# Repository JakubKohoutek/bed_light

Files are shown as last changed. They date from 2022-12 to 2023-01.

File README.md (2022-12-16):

# WiFi enabled bed light

LED light triggered by PIR motion sensor and connected to Alexa using ESP8266.
Original purpose is the night light under the bed, but the usage is actually universal.

## Circuit Diagram

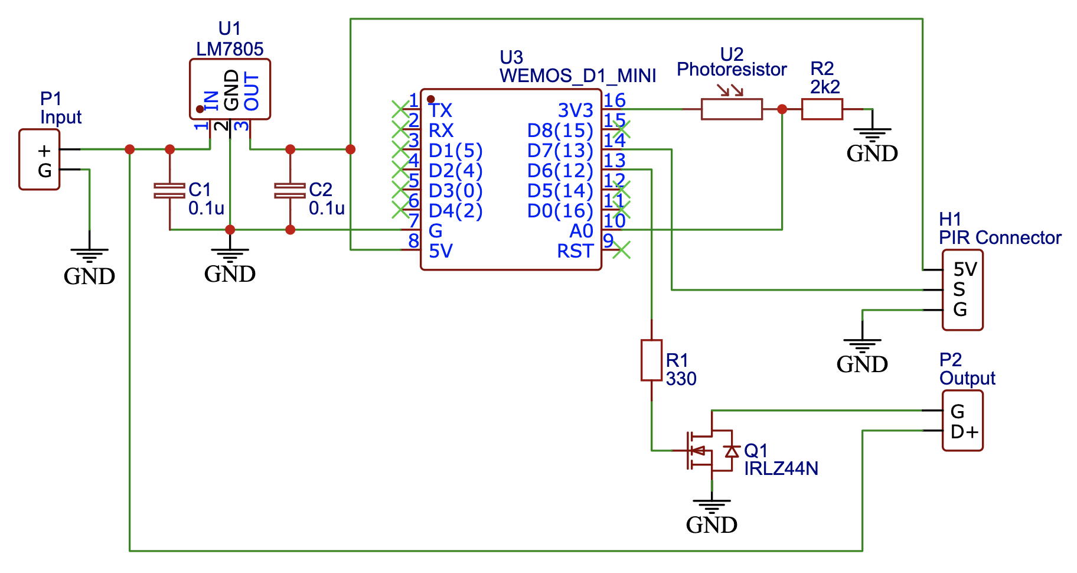
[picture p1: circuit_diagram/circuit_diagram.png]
Circuit Diagram


## Remote console

When the module is connected to WiFi, there is a remote console available at the
http://\<Device IP\>/webserial url. The list of possible commands is provided when the `help`
command is sent there.

## PIR Sensor vs WiFi

During the testing, I realized the PIR sensor is very sensitive and there are
many false triggers. The main reason is actually the WiFi of the ESP8266 - the
noise caused by the WiFi chip is triggering the sensor if there is some spike
in the network activity.

There are several measures I've taken to prevent this from happening:
- Include ferrite bead and capacitors on the PIR's supply voltage and signal
  line, just as [this article](https://www.kevindarrah.com/wiki/index.php?title=TrigBoardMotion)
  suggests.
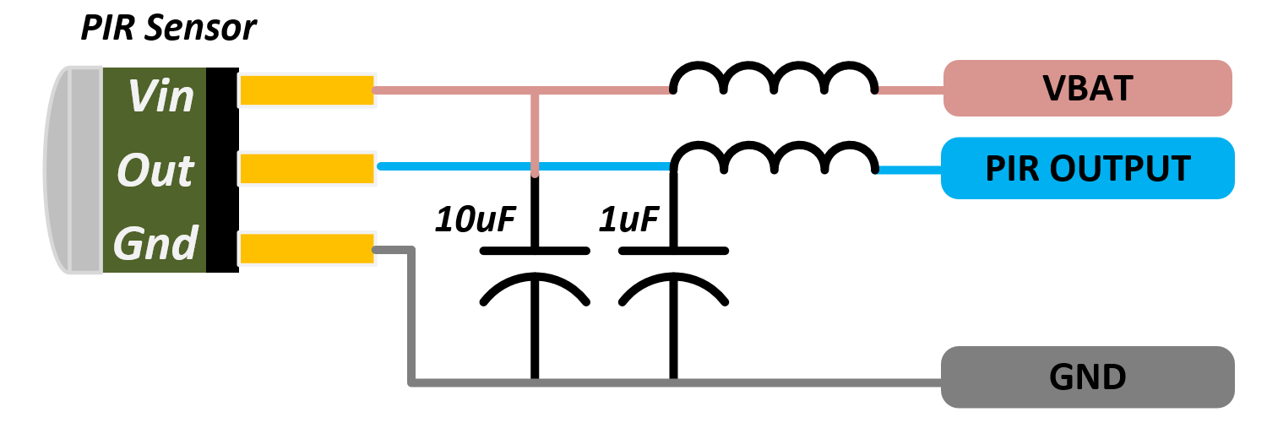
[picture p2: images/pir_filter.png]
PIR filter diagram
  
- Use grounded copper tape to cover the power and signal traces on the PCB leading to the PIR sensor
- Wrapped the head of the PIR sensor with the copper tape and used a piece of tube on
  the sensor head (that blocks the IR light) to block the IR noise

These measures reduced the amount of false triggers to a minimum, almost zero.

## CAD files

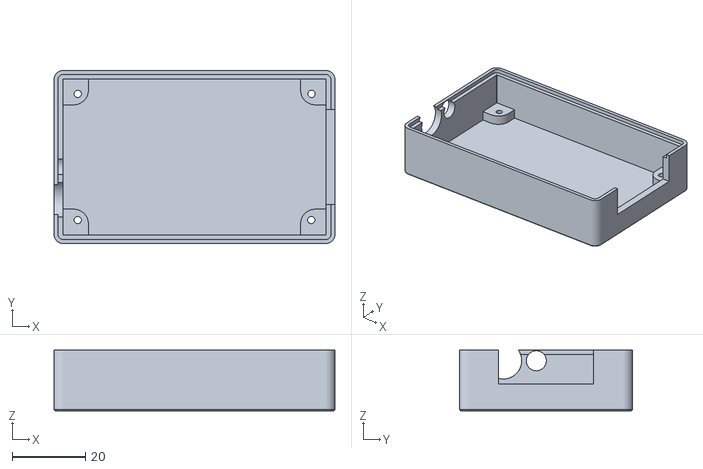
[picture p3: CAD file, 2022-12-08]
housing_model/Lower_part_v1.stl
76.8 x 47.3 x 16.6

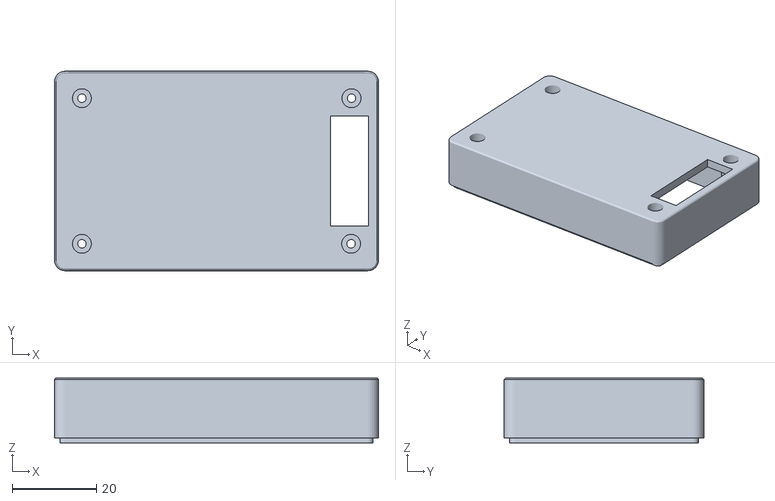
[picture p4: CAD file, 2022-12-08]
housing_model/Upper_part_v1.stl
76.8 x 47.3 x 15.4

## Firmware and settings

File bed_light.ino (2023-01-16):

#include <ESP8266WiFi.h>
#include <ESPAsyncWebServer.h>
#include <fauxmoESP.h>
#include <WebSerial.h>
#include <credentials.h>
#include "ota.h"
#include "memory.h"

#define LED_PIN D6
#define PIR_PIN D7
#define LDR_PIN A0

enum State { steady, fadingIn, fadingOut };

fauxmoESP      fauxmo;
AsyncWebServer server(80);
const char*    ssid                     = STASSID;
const char*    password                 = STAPSK;
const char*    deviceId                 = "Jacob's bed light";
State          currentState             = steady;
int            ledStripBrightness       = 0;
int            brightnessMemoryAddress  = 0;
int            thresholdMemoryAddress   = 4;
int            falseAlertsMemoryAddress = 8;
int            timeoutMemoryAddress     = 12;
int            badAlarmThresholdAddress = 16;
int            maximumBrightness        = 255;
int            roomBrightness           = 0;
int            roomBrightnessThreshold  = 100;
int            timeOfLastProcessing     = millis();
int            timeOfLastTrigger        = millis();
int            timeOflastInterrupt      = 0;
int            timeOfSensorSwitchOff    = 0;
bool           controlledByAssistant    = false;
int            falsePositivesCount      = 0;
int            lastFalsePositivesCount  = 0;
int            lightOnTimeout           = 30 * 1000;
boolean        isDelayedSwitchOff       = false;
int            falseAlarmThreshold      = 6320;

volatile boolean hasInterruptToProcess  = false;

void turnOffWiFi() {
    WiFi.disconnect();
    WiFi.mode(WIFI_OFF);
}

void turnOnWiFi() {
    WiFi.mode(WIFI_STA);
    WiFi.begin(ssid, password);
    while (WiFi.status() != WL_CONNECTED){
        delay(500);
    }
}

void ICACHE_RAM_ATTR handleSensorChange() {
    hasInterruptToProcess = true;
}

void setup() {
    pinMode(LED_PIN,     OUTPUT);
    pinMode(PIR_PIN,     INPUT);
    pinMode(LED_BUILTIN, OUTPUT);

    turnOnWiFi();

    // Inititate eeprom memory
    initiateMemory();

    // erase memory, only on the first upload
    // writeToMemory(brightnessMemoryAddress, 0);
    // writeToMemory(thresholdMemoryAddress, roomBrightnessThreshold);
    // writeToMemory(timeoutMemoryAddress, lightOnTimeout);
    // writeToMemory(badAlarmThresholdAddress, falseAlarmThreshold);

    maximumBrightness = readFromMemory(brightnessMemoryAddress);
    roomBrightnessThreshold = readFromMemory(thresholdMemoryAddress);
    lastFalsePositivesCount = readFromMemory(falseAlertsMemoryAddress);
    writeToMemory(falseAlertsMemoryAddress, 0);
    lightOnTimeout = readFromMemory(timeoutMemoryAddress);
    falseAlarmThreshold = readFromMemory(badAlarmThresholdAddress);

    // Initiate over the air programming
    OTA::initialize(deviceId);

    // Configure connection to home assistants
    fauxmo.createServer(false);
    fauxmo.setPort(80);
    fauxmo.addDevice(deviceId);
    fauxmo.enable(true);

    fauxmo.onSetState([](unsigned char device_id, const char * device_name, bool switchedOn, unsigned char value) {
        String statusMessage = String("[MAIN] Device ") + "device_id" + "(" + device_name + ") state: " + (switchedOn ? "ON" : "OFF") + ", value: " + value;
        WebSerial.println(statusMessage);

        maximumBrightness = value;
        writeToMemory(brightnessMemoryAddress, value);
        controlledByAssistant = switchedOn;
        if (switchedOn) {
            currentState = fadingIn;
        } else {
            currentState = fadingOut;
        }
    });

    // WebSerial is accessible at "<IP Address>/webserial" in browser
    WebSerial.begin(&server);
    WebSerial.msgCallback(handleWebSerialMessage);

    server.on("/index.html", HTTP_GET, [](AsyncWebServerRequest *request){
        request->send(200, "text/plain", (String("The room brightness is ") + String(roomBrightness)).c_str());
    });

    server.onRequestBody([](AsyncWebServerRequest *request, uint8_t *data, size_t len, size_t index, size_t total) {
        if (fauxmo.process(request->client(), request->method() == HTTP_GET, request->url(), String((char *)data))) return;
        // Handle any other body request here...
    });

    server.onNotFound([](AsyncWebServerRequest *request) {
        String body = (request->hasParam("body", true)) ? request->getParam("body", true)->value() : String();
        if (fauxmo.process(request->client(), request->method() == HTTP_GET, request->url(), body)) return;
        request->send(404, "text/plain", "Sorry, not found. Did you mean to go to /webserial ?");
    });

    server.begin();

    attachInterrupt(PIR_PIN, handleSensorChange, CHANGE);
}

void handleWebSerialMessage(uint8_t *data, size_t len){
    // Process message into command:value pair  
    String command = "";
    String value   = "";
    boolean beforeColon = true;
    for(int i=0; i < len; i++){
        if (char(data[i]) == ':'){
            beforeColon = false;
        } else if (beforeColon) {
            command += char(data[i]);
        } else {
            value += char(data[i]);
        }
    }

    if(command.equals("setBrightnessThreshold")) {
        WebSerial.println(String("Setting brightness threshold to ") + value.toInt());
        roomBrightnessThreshold = value.toInt();
        writeToMemory(thresholdMemoryAddress, roomBrightnessThreshold);
    } else
    if(command.equals("getBrightnessThreshold")) {
        WebSerial.println(String("Brightness threshold is ") + roomBrightnessThreshold);
    } else 
    if(command.equals("getBrightness")) {
        WebSerial.println(String("Brightness is ") + readRoomBrightness());
    } else 
    if(command.equals("sleepWiFi")) {
        WebSerial.println("Putting WiFi to sleep. To enable it again, you have to restart the device.");
        turnOffWiFi();
    } else
    if(command.equals("getFalsePositives")) {
        WebSerial.println(String("Number of false positives since the start: ") + falsePositivesCount);
    } else
    if(command.equals("getPreviousFalsePositives")) {
        WebSerial.println(String("Number of false positives in the last run: ") + lastFalsePositivesCount);
    } else
    if(command.equals("getTimeout")) {
        WebSerial.println(String("The light stays on ") + (lightOnTimeout / 1000) + " seconds afther the sensor switched off");
    } else
    if(command.equals("setTimeout")) {
        lightOnTimeout = value.toInt() * 1000;
        writeToMemory(timeoutMemoryAddress, lightOnTimeout);
        WebSerial.println(String("Timeout set to ") + (lightOnTimeout / 1000) + " seconds");
    } else
    if(command.equals("getFalseAlarmThreshold")) {
        WebSerial.println(String("The false alarm threshold is ") + falseAlarmThreshold + " milliseconds");
    } else
    if(command.equals("setFalseAlarmThreshold")) {
        falseAlarmThreshold = value.toInt();
        writeToMemory(badAlarmThresholdAddress, falseAlarmThreshold);
        WebSerial.println(String("False alarm threshold set to ") + falseAlarmThreshold + " milliseconds");
    } else
    if(command.equals("help")) {
        WebSerial.println((
          String("Available commands:\n") +
          "getBrightnessThreshold\n" +
          "setBrightnessThreshold:value\n" +
          "getBrightness\n" +
          "sleepWiFi\n" +
          "getFalsePositives\n" +
          "getPreviousFalsePositives\n" +
          "getTimeout\n" +
          "setTimeout:value\n" +
          "getFalseAlarmThreshold\n" +
          "setFalseAlarmThreshold:value\n"
        ).c_str());
    } else {
        WebSerial.println(String("Unknown command '") + command + "' with value '" + value +"'" + value);
    }
}

int readRoomBrightness () {
    // analogRead (namely the ADC) sometimes conflicts with the WiFi and Server request processing
    // we can't use it on every loop iteration, but only sometimes, on demand!
    roomBrightness = analogRead(LDR_PIN);

    return roomBrightness;
}

void handleLightChangeEvents () {
    int currentTime = millis();
    if (currentTime - timeOfLastProcessing < 2) {
        return;
    }
    timeOfLastProcessing = currentTime;
    
    switch (currentState) {
        case steady:
            analogWrite(LED_PIN, ledStripBrightness);
            break;
        case fadingIn:
            if (ledStripBrightness < maximumBrightness) {
                analogWrite(LED_PIN, ++ledStripBrightness);
            } else 
            if (ledStripBrightness > maximumBrightness) {
                analogWrite(LED_PIN, --ledStripBrightness);
            } else {
                currentState = steady;
            }
            break;
        case fadingOut:
            if (ledStripBrightness > 0) {
                analogWrite(LED_PIN, --ledStripBrightness);
            } else {
                currentState = steady;
            }
            break;
        default:
            currentState = steady;
    }
}

void processInterrupt() {
    if(!hasInterruptToProcess) {
        return;
    }

    // debounce the interrupt as it might trigger twice
    if(hasInterruptToProcess && millis() - timeOflastInterrupt < 10) {
        hasInterruptToProcess = false;
        return;
    }

    hasInterruptToProcess = false;
    timeOflastInterrupt = millis();

    // It can take upt to 4 milliseconds for the sensor to switch fully the state,
    // therefore we wait until it happens and the sensor value is reliable
    delay(4);

    if(digitalRead(PIR_PIN) == HIGH) {
        digitalWrite(LED_BUILTIN, LOW);
        timeOfLastTrigger = millis();
        isDelayedSwitchOff = false;
        readRoomBrightness();
        if (!controlledByAssistant && roomBrightness < roomBrightnessThreshold) {
            currentState = fadingIn;
        }
        WebSerial.println("[MAIN] Sensor switched on");
    } else {
        digitalWrite(LED_BUILTIN, HIGH);
        timeOfSensorSwitchOff = millis();
        float sensorOnTime = (float)(timeOfSensorSwitchOff - timeOfLastTrigger)/1000;
        boolean isFalseAlarm = sensorOnTime < (float)falseAlarmThreshold / 1000;
        WebSerial.println(String("[MAIN] Sensor switched off after ") + sensorOnTime + " seconds");
        if (!controlledByAssistant) {
            if(isFalseAlarm) {
                // turn off the light immediately if we know it's a false alarm
                currentState = fadingOut;
                writeToMemory(falseAlertsMemoryAddress, ++falsePositivesCount);
            } else {
                isDelayedSwitchOff = true;
            }
        }
    }
}

void loop() {
    fauxmo.handle();
    OTA::handle();
    handleLightChangeEvents();
    processInterrupt();

    // handle delayed switch off
    if(isDelayedSwitchOff && millis() - timeOfSensorSwitchOff > lightOnTimeout) {
        isDelayedSwitchOff = false;
        currentState = fadingOut;
        WebSerial.println(String("[MAIN] Light switched off after another ") + (float)((millis() - timeOfSensorSwitchOff)/1000) + " seconds");
    }
}

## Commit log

2022-11-07 Include LED strip and sensor in the code
2022-11-14 Add light dependent resistor
2022-12-08 Add housing model and circuit diagram
    [Lower_part_v1.stl, Upper_part_v1.stl]
2022-12-21 Keep light on for some time even after sensor switches off
2022-12-21 Use interrupt and make timeout configurable
2022-12-22 Fix lights not shutting down sometimes
    [bed_light.ino]
2022-12-27 Refactor to remove bug with incorrenct sensor value
    [bed_light.ino]
2023-01-16 Fix incorrect condition when controlled by assistant
    [bed_light.ino]
